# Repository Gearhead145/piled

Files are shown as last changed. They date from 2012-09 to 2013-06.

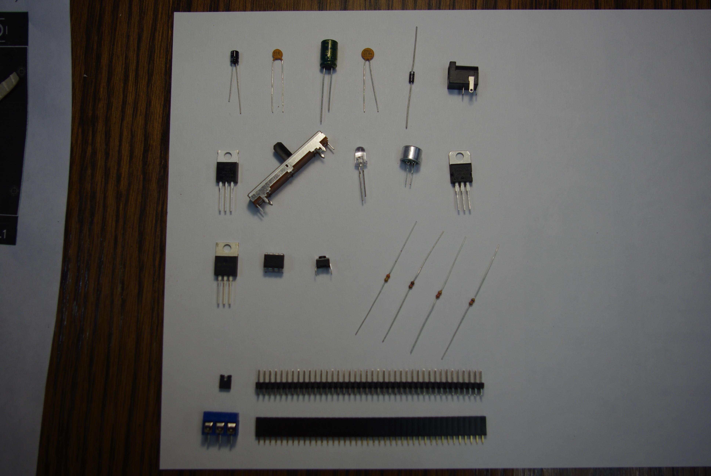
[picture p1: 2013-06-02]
Component Datasheets/PILED/113_0601/IMGP3082.JPG

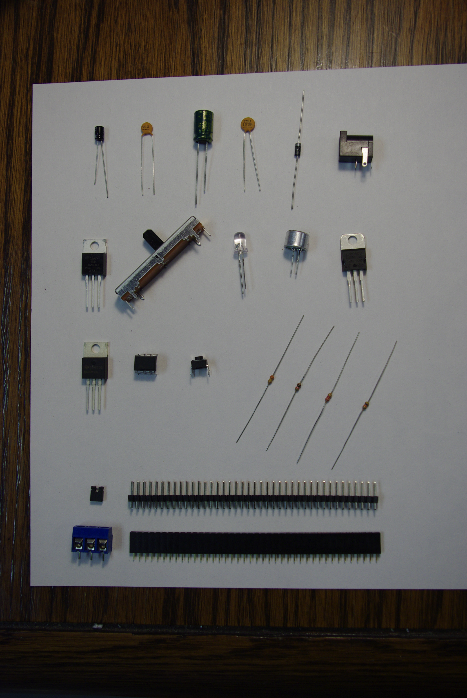
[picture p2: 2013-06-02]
Component Datasheets/PILED/113_0601/IMGP3088.JPG

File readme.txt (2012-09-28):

*Note - For best appearance, view with a monospaced font with word-wrap disabled* 

                 ___      _______  ______     _______  ___   ___      _______ 
                |   |    |       ||      |   |       ||   | |   |    |       |
                |   |    |    ___||  _    |  |_     _||   | |   |    |    ___|
                |   |    |   |___ | | |   |    |   |  |   | |   |    |   |___ 
                |   |___ |    ___|| |_|   |    |   |  |   | |   |___ |    ___|
                |       ||   |___ |       |    |   |  |   | |       ||   |___ 
                |_______||_______||______|     |___|  |___| |_______||_______|

                              More than just another LED desk lamp.

                          - An Open-Source Hardware/Software project -

The LED TILE is a MSP430G2553 based development board with integrated high current constant
voltage LED drivers, input sensors, and fully configurable I/O. Female headers allow easy addition
of sensors and other devices, while shorting blocks can be used to enable or disable any of the on-board 
devices (such as the LED Drivers or Microphone). On board voltage regulators produce 3.3V and 5V, which
are available via a female header for use with added circuits.

Hardware Features [Mainboard] :
	-3 channels (RGB) MOSFET based LED outputs (each 1.5A continuous!)
	-Electret microphone, LM386 based pre-amplifier, hardware envelope and low pass filters
	-Three linear potentiometers
	-Two pushbuttons
	-Female header sockets for EVERY PIN on the microcontroller, allowing easy connection of
		sensors and additional circuits (such as additional buttons, CdS cell, etc)
	-Double Male headers allow you to selectively connect or disconnect ANY pin on the
		microcontroller to the main board circuitry using shorting blocks. This is important
		if you want to use I/O pins from the LED TILE sensors (such as the potentiometers)
		for your own sensors and circuits.
	-Screw Terminals for Input Power (12V), Inter-Tile Serial Communication Lines, LED Outputs
	-On-board voltage regulators produce 3.3V and 5V (and unregulated 12V), which are available 
		via female header for simple interface of custom sensors to the LED TILE
	-Constructed using through-hole components - Even a beginner can solder this board together!
		(also available fully soldered. The processor is surface mount, and is always pre-soldered)

MSP430G2553 / Software Features:
	-8 channels of 10bit ADCs (for reading analog values into the microcontroller, such as those
		from potentiometers, light sensors, or audio)
	-24 General Purpose digital I/O pins (for attaching buttons, etc)
	-16Kb of program memory offers space for moderately large programs (for example, the current
		LIGHT TILE demo code, which has several modes, including a smooth RGB fade, an adjustable
		color temperature light source, an RGB mixer, a sound activated DJ style fading light,
		and a variable color/frequency/duty cycle strobe, uses under 3Kb of memory)
	-Internal (enable-able) pull up/down resistors makes attaching a button as simple as connecting
		it from a I/O pin to ground or VCC
	-Integrated hardware UART allows for inter-TILE communication with virtually no cpu overhead. 
		While primarily designed to allow an array of LED TILEs to act as pixels and display 
		patterns, the serial can be used for just about anything.
	-Write new code to make the LED TILE do cool things!
	-We have created helper functions to make tasks (such as reading analog values from sensors) 
		simple and intuitive
	-The processor runs at up to 16MHz (even running at 1MHz, the demo program runs fast enough to
		refresh the LEDs around 4000 times a second)
	-Can be easily programmed via the Spy-Bi-Wire interface. We reccomend using a TI Launchpad as 
		a programmer (these cost only $4.30, including shipping/handling). Simply attach the
		launchpad with four jumpers (VSS,GND,RST,TEST) to the LED TILE, and connect the launchpad
		USB cable to the computer. The free version of Code Composer Studio provides a robust
		IDE and compiler, and can be used to develop code for the LED TILE.

Hardware Features [LEDs and interface board] :
	-One LED TILE complete kit includes 5.5 feet of RGB LED tape. 5.5 feet has 100 LEDs (each of 
		which is an surface mount 5050 RGB LED)
			-RGB LED Specs [each individual LED]:
				-100mW per color (300mW if all three are fully on)
				-Luminous Intensity Red: 800mcd, Green: 1000mcd, Blue: 400mcd
	-LED Tape can be cut every 3 LEDs - use long strips for lighting computers, desks, etc.
	-LED Tape is self adhesive and flexible, allowing creative mounting...
	-The LED TILE LED Interface Board can be used to connect 9 strips (each of 9 leds) to form an
		array of 81 LEDs. This is bright enough to be used as a small desk lamp, and can easily
		provide mood/accent light for a decent sized room. This board has solder pads for each
		strip, which eliminates the need to cut many pieces of wire.

******************************************************************************************************
*           LED TILE Mainboard: Schematic layout of interface components/sensors                     *
******************************************************************************************************
*                                                                                                    *
*                                                                                                    *
*             ┌────Three linear potentiometers [available as analog inputs to the microcontroller]   *
*             │                                                                                      *
*             │                                                                                      *
*         ┌───┼───┐  Two tactile switches          ┌──Female headers for 3.3V,5V,12V,GND             *
*         │   │   │        │                       │                                                 *
*       __│___│___│________│_______________________│_______                                          *
*      | _v  _v  _v   __   │                    ◘  │    [+]<─┐                                       *
*      ||  ||▐▌||  | |()|<─┤                    ◘<─┘    [+]<─┤                                       *
*      ||  ||▐▌||  | |__|  │                    ◘       [+]<─┤                                       *
*      ||  ||  ||  |       │                    ◘       [+]<─┼───Screw terminals for                 *
*      ||▐▌||  ||  |       │       ::::::::::::::<─┐    [+]<─┤   Input Power,Inter-Tile Serial,LEDS  *
*      ||▐▌||  ||  |       │  ┌───>◘◘◘◘◘◘◘◘◘◘◘◘◘◘  │    [+]<─┤                                       *
*      ||  ||  ||  |       │  │    ____            │    [+]<─┤                                       *
*      ||  ||  ||  |       │  │   /    \           │    [+]<─┘                                       *
*      ||  ||  ||  |       │  │   |Mic.|           │       |                                         *
*      ||  ||  ||  |       │  │   \____/           │       |                                         *
*      ||  ||  ||  |       │  │                    │       |                                         *
*      ||  ||  ||▐▌|  __   │  ├───>◘◘◘◘◘◘◘◘◘◘◘◘◘◘  │       |                                         *
*      ||  ||  ||▐▌| |()|<─┘  │    ::::::::::::::<─┤       |                                         *
*      ||__||__||__| |__|     │                    │       |                                         *
*      |______________________│____________________│_______|                                         *
*                             │                    │                                                 *
*                 Single female headers      Double male headers                                     *
*                 Easily attach DIY sensors  [Enable/disable on-board devices]                       *
*                                                                                                    *
******************************************************************************************************

******************************************************************************************************
*                           LED TILE LightBoard: Interface Schematic                                 *
******************************************************************************************************
*   ┌────────────────────────────────────────────────────────────────────────────────────────┬────┐  *
*   │                                                                                        │    │  *
*   v________________________________________________________________________________________v    │  *
*  |○                                                                                        ○|   │  *
*  |○                                                                                        ○|   │  *
*  |○                                                                                        ○|   │  *
*  |○__⌂⌂⌂⌂______⌂⌂⌂⌂______⌂⌂⌂⌂______⌂⌂⌂⌂______⌂⌂⌂⌂______⌂⌂⌂⌂______⌂⌂⌂⌂______⌂⌂⌂⌂______⌂⌂⌂⌂__○|   │  *
*        ^         ^         ^         ^         ^         ^         ^         ^         ^        │  *
*        │         │         │         │         │         │         │         │         │        │  *
*        ├─────────┴─────────┴─────────┴─────────┴─────────┴─────────┴─────────┴─────────┘        │  *
*        │                                                                                        │  *
*        └── Solder pads to connect individual strips of LED Tape                                 │  *
*                                                                                                 │  *
*                                           Drilled solder pad connections for LED TILE Mainboard─┘  *
*                                                                                                    *
******************************************************************************************************

******************************************************************************************************
*                LED TILE LightBoard: Suggested LED Configuration [ 81 RGB LEDs]                     *
******************************************************************************************************
*                                                                                                    *
*     __________________________________________________________________________________________     *
*    |○                                                                                        ○|    *
*    |○                                                                                        ○|    *
*    |○                                                                                        ○|    *
*    |○__⌂⌂⌂⌂______⌂⌂⌂⌂______⌂⌂⌂⌂______⌂⌂⌂⌂______⌂⌂⌂⌂______⌂⌂⌂⌂______⌂⌂⌂⌂______⌂⌂⌂⌂______⌂⌂⌂⌂__○|    *
*       |    |    |    |    |    |    |    |    |    |    |    |    |    |    |    |    |    |       *
*       |┌──┐|    |┌──┐|    |┌──┐|    |┌──┐|    |┌──┐|    |┌──┐|    |┌──┐|    |┌──┐|    |┌──┐|       *
*       |└──┘|    |└──┘|    |└──┘|    |└──┘|    |└──┘|    |└──┘|    |└──┘|    |└──┘|    |└──┘|       *
*       |    |    |    |    |    |    |    |    |    |    |    |    |    |    |    |    |    |       *
*       |    |    |    |    |    |    |    |    |    |    |    |    |    |    |    |    |    |       *
*       |    |    |    |    |    |    |    |    |    |    |    |    |    |    |    |    |    |       *
*       |┌──┐|    |┌──┐|    |┌──┐|    |┌──┐|    |┌──┐|    |┌──┐|    |┌──┐|    |┌──┐|    |┌──┐|       *
*       |└──┘|    |└──┘|    |└──┘|    |└──┘|    |└──┘|    |└──┘|    |└──┘|    |└──┘|    |└──┘|       *
*       |    |    |    |    |    |    |    |    |    |    |    |    |    |    |    |    |    |       *
*       |    |    |    |    |    |    |    |    |    |    |    |    |    |    |    |    |    |       *
*       |    |    |    |    |    |    |    |    |    |    |    |    |    |    |    |    |    |       *
*       |┌──┐|    |┌──┐|    |┌──┐|    |┌──┐|    |┌──┐|    |┌──┐|    |┌──┐|    |┌──┐|    |┌──┐|       *
*       |└──┘|    |└──┘|    |└──┘|    |└──┘|    |└──┘|    |└──┘|    |└──┘|    |└──┘|    |└──┘|       *
*       |    |    |    |    |    |    |    |    |    |    |    |    |    |    |    |    |    |       *
*       |    |    |    |    |    |    |    |    |    |    |    |    |    |    |    |    |    |       *
*       |    |    |    |    |    |    |    |    |    |    |    |    |    |    |    |    |    |       *
*       |┌──┐|    |┌──┐|    |┌──┐|    |┌──┐|    |┌──┐|    |┌──┐|    |┌──┐|    |┌──┐|    |┌──┐|       *
*       |└──┘|    |└──┘|    |└──┘|    |└──┘|    |└──┘|    |└──┘|    |└──┘|    |└──┘|    |└──┘|       *
*       |    |    |    |    |    |    |    |    |    |    |    |    |    |    |    |    |    |       *
*       |    |    |    |    |    |    |    |    |    |    |    |    |    |    |    |    |    |       *
*       |    |    |    |    |    |    |    |    |    |    |    |    |    |    |    |    |    |       *
*       |┌──┐|    |┌──┐|    |┌──┐|    |┌──┐|    |┌──┐|    |┌──┐|    |┌──┐|    |┌──┐|    |┌──┐|       *
*       |└──┘|    |└──┘|    |└──┘|    |└──┘|    |└──┘|    |└──┘|    |└──┘|    |└──┘|    |└──┘|       *
*       |    |    |    |    |    |    |    |    |    |    |    |    |    |    |    |    |    |       *
*       |    |    |    |    |    |    |    |    |    |    |    |    |    |    |    |    |    |       *
*       |    |    |    |    |    |    |    |    |    |    |    |    |    |    |    |    |    |       *
*       |┌──┐|    |┌──┐|    |┌──┐|    |┌──┐|    |┌──┐|    |┌──┐|    |┌──┐|    |┌──┐|    |┌──┐|       *
*       |└──┘|    |└──┘|    |└──┘|    |└──┘|    |└──┘|    |└──┘|    |└──┘|    |└──┘|    |└──┘|       *
*       |    |    |    |    |    |    |    |    |    |    |    |    |    |    |    |    |    |       *
*       |    |    |    |    |    |    |    |    |    |    |    |    |    |    |    |    |    |       *
*       |    |    |    |    |    |    |    |    |    |    |    |    |    |    |    |    |    |       *
*       |┌──┐|    |┌──┐|    |┌──┐|    |┌──┐|    |┌──┐|    |┌──┐|    |┌──┐|    |┌──┐|    |┌──┐|       *
*       |└──┘|    |└──┘|    |└──┘|    |└──┘|    |└──┘|    |└──┘|    |└──┘|    |└──┘|    |└──┘|       *
*       |    |    |    |    |    |    |    |    |    |    |    |    |    |    |    |    |    |       *
*       |    |    |    |    |    |    |    |    |    |    |    |    |    |    |    |    |    |       *
*       |    |    |    |    |    |    |    |    |    |    |    |    |    |    |    |    |    |       *
*       |┌──┐|    |┌──┐|    |┌──┐|    |┌──┐|    |┌──┐|    |┌──┐|    |┌──┐|    |┌──┐|    |┌──┐|       *
*       |└──┘|    |└──┘|    |└──┘|    |└──┘|    |└──┘|    |└──┘|    |└──┘|    |└──┘|    |└──┘|       *
*       |    |    |    |    |    |    |    |    |    |    |    |    |    |    |    |    |    |       *
*       |    |    |    |    |    |    |    |    |    |    |    |    |    |    |    |    |    |       *
*       |    |    |    |    |    |    |    |    |    |    |    |    |    |    |    |    |    |       *
*       |┌──┐|    |┌──┐|    |┌──┐|    |┌──┐|    |┌──┐|    |┌──┐|    |┌──┐|    |┌──┐|    |┌──┐|       *
*       |└──┘|    |└──┘|    |└──┘|    |└──┘|    |└──┘|    |└──┘|    |└──┘|    |└──┘|    |└──┘|       *
*       |    |    |    |    |    |    |    |    |    |    |    |    |    |    |    |    |    |       *
*       |____|    |____|    |____|    |____|    |____|    |____|    |____|    |____|    |____|       *
*                                                                                                    *
*                                                                                                    *
******************************************************************************************************

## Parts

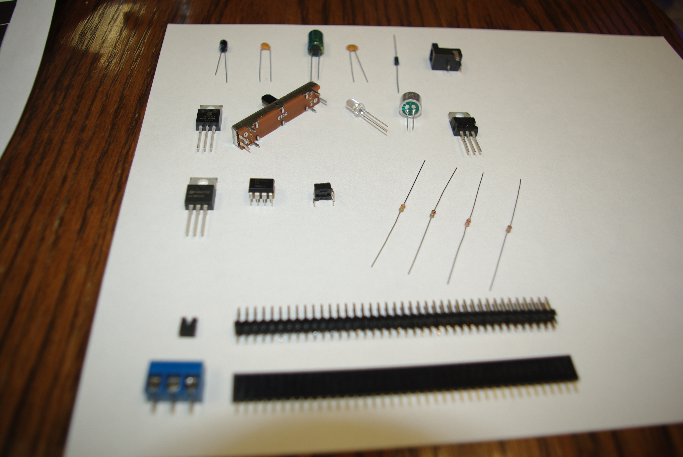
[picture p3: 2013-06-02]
Component Datasheets/PILED/113_0601/IMGP3078.JPG

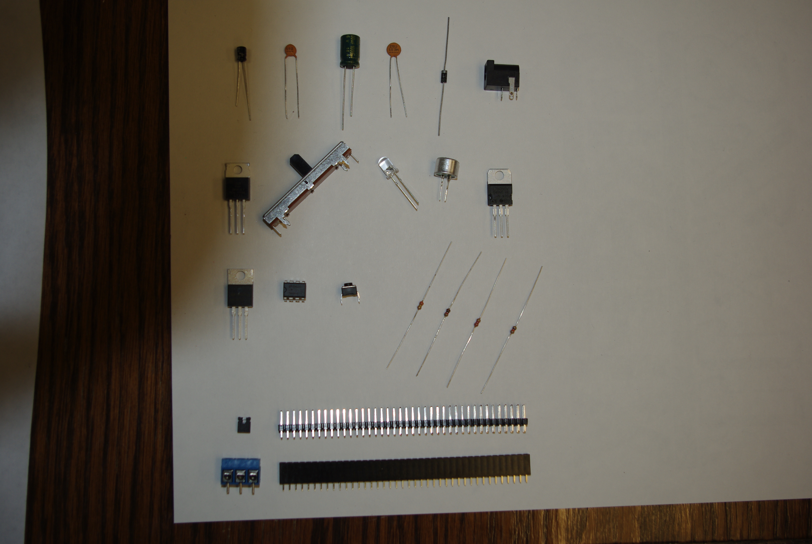
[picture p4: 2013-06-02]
Component Datasheets/PILED/113_0601/IMGP3077.JPG

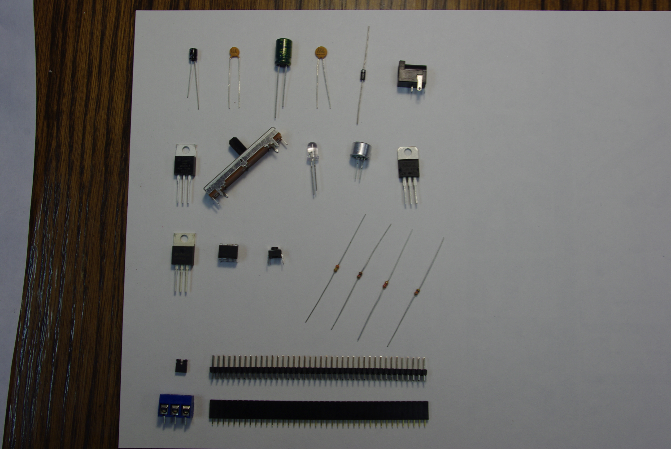
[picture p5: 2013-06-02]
Component Datasheets/PILED/113_0601/IMGP3084.JPG

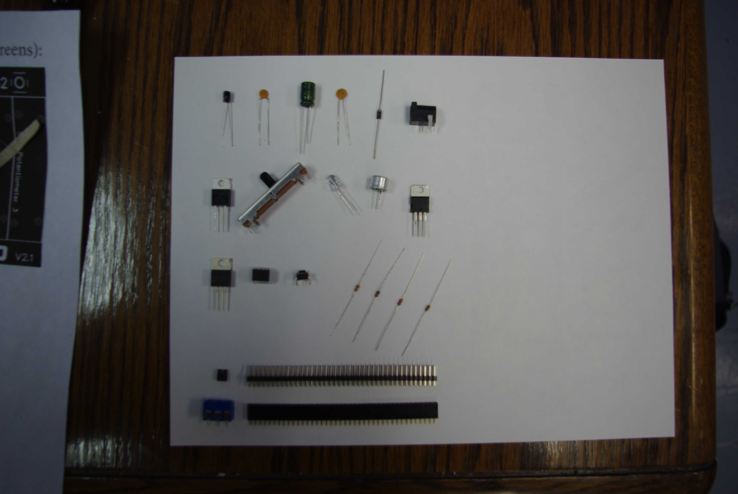
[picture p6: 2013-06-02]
Component Datasheets/PILED/113_0601/IMGP3081.JPG

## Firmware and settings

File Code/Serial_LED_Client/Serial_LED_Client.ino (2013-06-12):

#include "test.h" //Include VITAL RGB TILE FUNCTIONS!
#define mode_max 6//Define the maximum number of modes, so the pushbuttons will iterate through them all properly. Mode 0 is direct bluetooth command, and Mode 1 is the default start-up mode (rgb mixer). 
unsigned char mode = 1; //Global mode variable allows board to save/switch between different operating modes.


//Settings for strobe
char s_r = 255;
char s_g = 255;
char s_b = 255;

//setting for sound activated colors
char ccolor = 0;
int avg = 1023; //variable for keeping a running average of the sound levels. Start at 1023 to prevent accidental triggering in a low volume situation

//setting for rainbow fade
// global variables
unsigned int rbow;     //0-360
unsigned int relative; //0-59
unsigned char rr, rg, rb;

//setting for clap activated white light
boolean clapper = 0;


void _set_rgb(char command[128], char command_length, char base_length){
  //parse out the individual strings
  char temp_num[4]; //3 chars, plus a null character to terminate it as a string for atoi()
  char color = 2;
  char pos;
  char temp = command_length - 3; //we want an index of the leftmost data value (not ")" or ";" )
  unsigned char r,g,b;
  while ( temp > base_length){
     temp_num[0] = '0';//clear the buffer for a single color
     temp_num[1] = '0';
     temp_num[2] = '0';
     temp_num[3] = 0; //null character termination
     pos = 2;
    while (command[temp] != ',' && command[temp] != '('){ //parse out separate colors
        temp_num[pos] = command[temp]; //data? I hope so!
        temp--;
        pos--;
        if (pos<-1) { //You forgot a comma, or put WAY too many digits...
           invalid_input();
           return;
        }
    }
    temp--;

    //the temp_num array should now contain a 3 digit padded null terminated ascii representation of a number
    if (color == 2) b = atoi(temp_num);
    if (color == 1) g = atoi(temp_num);
    if (color == 0) r = atoi(temp_num);
    color--; //now read in the next color   
  }
  set_rgb(r,g,b);
}


void _target_rgb(char command[128], char command_length, char base_length){
  
  //!!! THIS IS A BLOCKING COMMAND!!!
 
  //parse out the individual strings
  char temp_num[11]; //10 chars, plus a null character to terminate it as a string for atoi()
  char color = 3; //color here also includes the target time
  char pos;
  char temp = command_length - 3; //we want an index of the leftmost data value (not ")" or ";" )
  unsigned char r,g,b;
  unsigned int t; //store the target fade time
  
  while ( temp > base_length){
     temp_num[0] = '0';//clear the buffer for a single color
     temp_num[1] = '0';
     temp_num[2] = '0';
     temp_num[3] = '0';
     temp_num[4] = '0';
     temp_num[5] = '0';
     temp_num[6] = '0';
     temp_num[7] = '0';
     temp_num[8] = '0';
     temp_num[9] = '0';
     temp_num[10] = '0';
     temp_num[11] = 0; //null character termination
     pos = 10;
    while (command[temp] != ',' && command[temp] != '('){ //parse out separate colors
        temp_num[pos] = command[temp]; //data? I hope so!
        temp--;
        pos--;
        if (pos<-1) { //You forgot a comma, or put WAY too many digits...
           invalid_input();
           return;
        }
    }
    temp--;

    //the temp_num array should now contain a 3 digit padded null terminated ascii representation of a number
    if (color == 3) t = atoi(temp_num);
    if (color == 2) b = atoi(temp_num);
    if (color == 1) g = atoi(temp_num);
    if (color == 0) r = atoi(temp_num);
    color--; //now read in the next color   
  }
  target_rgb(r,g,b,t);  
}

void reboot(){
  set_rgb(0,0,0);
  s_r = 255;
  s_g = 255;
  s_b = 255;
  avg = 1023;//reset the sound average.
  setup();
}


 void invalid_input(){
   Serial.println("Error in input command. Type ""help();"" for available commands."); 
 }

void establishContact() {
  Serial.println(" _______  ___   ___      _______  ______"); 
  Serial.println("|       ||   | |   |    |       ||      |");
  Serial.println("|    _  ||   | |   |    |    ___||  _    |");
  Serial.println("|   |_| ||   | |   |    |   |___ | | |   |");
  Serial.println("|    ___||   | |   |___ |    ___|| |_|   |");
  Serial.println("|   |    |   | |       ||   |___ |       |");
  Serial.println("|___|    |___| |_______||_______||______|");
  Serial.println("\nSerial command shell v1.2");
  Serial.println("Copyright 2012 LIB3 Inc.");
  Serial.println("__________________________________________\n\n");
  Serial.print('>');
}



//dec_mode and inc_mode serve as the ISR functions for the two pushbuttons
void dec_mode(){
  mode--;
  if (mode == 0){
    mode = mode_max; //if we cycle to the end, continue at other end
  }
}

void inc_mode(){
  mode++;
  if (mode > mode_max){
    mode = 1;
  }  
}


void setup()
{
       setup_piled();
       mode = 1;          //Defaults to RGB mixer mode. 
       establishContact();  // send the fun initialization data OUT     
}

void loop()
{
  //Variables for serial parsing
char command[32]; //command buffer
int command_length = 0; //length of command (ending with a ;)
char command_temp = 0;
int base_length = 0;
  //Check mode, and do mode-specific stuff\
  
  while (1){
    
  int i;
  {
    switch (mode){
          case 0:{ // Direct bluetooth command mode. Do nothing - just wait for commands
            break;
          }
          case 1:
            set_rgb(analogRead(F1)/4, analogRead(F2)/4, analogRead(F3)/4);
            break;
          case 2: //the Clapper (named after Zach Clapper, creator of the first PILED Android app)
            {
            int threshold = analogRead(F1); //set the threshold from the F1 potentiometer. This is the level against which the mic signal is compared to detect transients
            int temp = analogRead(MIC);//value from 0-1023 indicating sound level. Room noise is around 100-150 with the air conditioner on... :D
      
      	    if (temp>threshold){ //if level is over threshold, it's a beat!
             //Clap on, clap off...
             if (clapper) {
               target_rgb((char)0,(char)0,(char)0,(unsigned int)200);
               clapper = 0;
             }
             else{
               target_rgb((char)255,(char)255,(char)255,(unsigned int)200);
               clapper = 1;
             }
            }
            break;
            }
          case 3:{
            int margin = analogRead(F1) / 16;//set the margin from the F1 potentiometer. This is the difference in the average level and a transient to trigger a beat.
            int temp = analogRead(MIC);//value from 0-1023 indicating sound level. Room noise is around 100-150 with the air conditioner on... :D
            avg  = (temp + 3*avg)/4; //commence with super simple running exponential averaging!  
      	    if (temp>(avg + margin)){ //if level is over average plus margin, it's a beat! (most of the time)   
              //Cycle through the colors
              if (ccolor == 2){
                 target_rgb((char)255,(char)0,(char)0,(unsigned int)10);
                 ccolor = 0;
               }              
               else if (ccolor == 1){
                 target_rgb((char)0,(char)255,(char)0,(unsigned int)10);
                 ccolor= 2;
               }
               else{
                  target_rgb((char)0,(char)0,(char)255,(unsigned int)10);
                  ccolor = 1;
               }
            }
            break;
          }
          case 4: //Color temperature fader F1
          {
            unsigned int ctemp = (analogRead(F1) / 8)-64;
            unsigned int bright = analogRead(F2)/4;
            set_rgb((bright*(191-ctemp))/256,(bright*(191))/256,(bright*(150+ctemp))/256);
            break;
          }
  	  case 5:
           {
            //strobe - with variable frequency, duty cycle, and color
            int ontime = analogRead(F1);
            int offtime = analogRead(F2);
            
	    sleep(offtime);//this is your off time...
            set_rgb(s_r,s_g,s_b); //Set the colors ON as requested...
	    sleep(ontime);//this is your on cycle time...
	    set_rgb(0,0,0);
            break;
           }
          case 6:
          {
            sleep(analogRead(F1)/64);
            rbow++;
            rbow %= 360;
            char category = rbow / 60;
            int relative = rbow % 60;
            switch(category){
              case 0:
                rr = 255;
                 rb = 0;
                 rg = relative * 17 / 4;
                           break;
              case 1:
                  rg = 255;
                  rb = 0;
                  rr = 255 - relative * 17 / 4;
                  break;
              case 2:
                  rg = 255;
                  rr = 0;
                  rb = relative * 17 / 4;
                  break;
              case 3:
                  rb = 255;
                  rr = 0;
                  rg = 255 - relative * 17 / 4;
                  break;
              case 4:
                  rb = 255;
                  rg = 0;
                  rr = relative * 17 / 4;
                  break;
              case 5:
                  rr = 255;
                  rg = 0;
                  rb = 255 - relative * 17 / 4;
                  break;
              }
              set_rgb(rr,rg,rb);
			  break;
          }     
    }
  }
  
  
   
  //check for serial stuff... Max length is 32 chars
  
    if (Serial.available() != 0){ //if there is a character in the serial buffer, check it!
      while (command_temp != ';'){
        command_temp = Serial.read();
        if (command_temp == ' ' || command_temp <= 31 || command_temp == '/r' || command_temp == '/n' ){
          //character is spacing/formatting, and should be ignored. Do nothing.
        }
        else { //character is valid, and should be treated as such...
          command[command_length] = command_temp;
          ++command_length; //update the recorded length of the command so far
          if (command_temp == '('){
            //This is the end of the base command, and the start of arguments
            base_length = command_length - 1;
          }
        }
      }
      if (command_temp == ';'){
        //We have a new command (perhaps!)
        //Now check which commands were requested! set_rgb, target_rgb, rgbmix, reboot, strobe, clapper

    
          if (!memcmp("target_rgb",command,10)){
            mode = 0;
             _target_rgb(command, command_length, base_length);
             //Prepare the console for a new command!
              command_length = 0; //length of command (ending with a ;)
              command_temp = 0;
              base_length = 0;
              Serial.write('\n>');
          }
          else if (!memcmp("set_rgb",command,7)){
            mode = 0;
            _set_rgb(command, command_length, base_length);
              //Prepare the console for a new command!
              command_length = 0; //length of command (ending with a ;)
              command_temp = 0;
              base_length = 0;
              Serial.write('\n>');
          }
          else if (!memcmp("rgbmix",command,6)){
            mode = 1; //set the mode to manual RGB faders
              command_length = 0; //length of command (ending with a ;)
              command_temp = 0;
              base_length = 0;
              Serial.write('\n>');
          }
          else if (!memcmp("clapper",command,7)){
            mode = 2; //set the mode to clap activated
              //Prepare the console for a new command!
              command_length = 0; //length of command (ending with a ;)
              command_temp = 0;
              base_length = 0;
              Serial.write('\n>');
          }
          
          else if (!memcmp("sound",command,5)){
            mode = 3; //set the mode to sound activated
              //Prepare the console for a new command!
              command_length = 0; //length of command (ending with a ;)
              command_temp = 0;
              base_length = 0;
              Serial.write('\n>');
          }
          else if (!memcmp("color_temp",command,10)){
            mode = 4; //set the mode to manual color temperature control
              //Prepare the console for a new command!
              command_length = 0; //length of command (ending with a ;)
              command_temp = 0;
              base_length = 0;
              Serial.write('\n>');
          }
          else if (!memcmp("rainbow",command,7)){
            mode = 6; //set the mode to demo rainbow mode
              //Prepare the console for a new command!
              command_length = 0; //length of command (ending with a ;)
              command_temp = 0;
              base_length = 0;
              Serial.write('\n>');
          }
          else if (!memcmp("strobe",command,6)){
            mode = 5; //set the mode to STROBE MODE (manual settings)
              //Prepare the console for a new command!
              command_length = 0; //length of command (ending with a ;)
              command_temp = 0;
              base_length = 0;
              Serial.write('\n>');
          }
          else if (!memcmp("reboot",command,6)){
              reboot();
              //Prepare the console for a new command!
              command_length = 0; //length of command (ending with a ;)
              command_temp = 0;
              base_length = 0;
              
          }   
          else {
            invalid_input();
              //Prepare the console for a new command!
              command_length = 0; //length of command (ending with a ;)
              command_temp = 0;
              base_length = 0;
              Serial.write('\n>');
          }                  
      }    
    }  
  }
}

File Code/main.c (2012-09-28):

//***************************************************************************************
//  MSP430 RGB LED Tile Control Software
//	Copyright 2012 Jorel Lalicki
//
//***************************************************************************************

//Board System Devices Port/Pin Numbers - These are NOT AVAILABLE FOR GENERAL USE unless disabled using shorting blocks:
// Port 1: ALL PINS
// Port 2: Pins 0,1,4



//Defines the on-board devices
//#define F1 INCH_7
//#define F2 INCH_5
//#define F3 INCH_4
//#define MIC INCH_0
//#define S1 BIT3 //Port 1
//#define S2 BIT0 //Port 2
//#define R BIT6 //Port 1
//#define G BIT1 //Port 2
//#define B BIT4 //Port 2



#include <msp430.h>				
#include "led_tile.h"
#include <stdlib.h>
//#include "launchpad_helpers.h"
int tempe;
char mode; //this global variable stores the current mode the LED TILE is operating in.
char rt;

//used for sound activated color rolling window averaging
char average[100];
char counter;


int main(void) //Program execution begins here:
{
	P1DIR &= ~BIT0;
	P1OUT &= ~BIT0;

	rt = 0;

	mode = 3; //This is the mode that the LED TILE will start in
	counter = 0;
	init();

  while(1){

	  int i;

   switch (mode){
  	  case 0:   {		  //very slow rgb fade

  			  target_rgb(255,0,0,1000000);
  			if (mode!= 0)break;

  			  target_rgb(255,255,0,1000000);
  			if (mode!= 0)break;

  			  target_rgb(0,255,0,1000000);
  			if (mode!= 0)break;

  			  target_rgb(0,255,255,1000000);
  			if (mode!= 0)break;

  			  target_rgb(0,0,255,1000000);
  			if (mode!= 0)break;

  			  target_rgb(255,0,255,1000000);
  		  break;
  	  }
//  	  case 1: //Sound Activated Color Thing! Quiet = blue, loud = RED
//  	  {
//  		  float gain = (float)Single_Measure(F1)/16+1; //set the gain from the R potentiometer - range 0-63
//  		  int threshold = Single_Measure(F2);//set the threshold from the R potentiometer
//  		  int temp = (Single_Measure(MIC));//value from 0-1023 indicating sound level. Room noise is around 100-150 with the air conditioner on... :D
//  		  temp -= threshold; //get rid of the ambient level
//  		  if (temp <0)temp=0; //if negative, make zero (leds cant show negative light)
//  		  temp*=gain; //multiply the level by 10 to get closer to the full LED brightness range
//  		  if (temp>255)temp=255; //if over the max level, make only the max level
//  		  //Keep a running average of 5 samples - this helps reduce flickering
//  		  int avg = 0;
//  		  int i;
//  		  for (i = 0; i < 100; i++){
//  			  avg += average[i];
//  		  }
//  		  avg /= 100;
//  		  average[counter] = temp;
//  		  counter++;
//  		  if (counter>=5)counter = 0;
//  		  target_rgb(255-avg,0,avg,1000);
//  		  break;
//  	  }
  	  case 1: //color temperature adjustment
  	  {
  		  int temp;
  		  temp = Single_Measure(F1) / 4;
  		  signed char offset = ((signed)temp - 128) / 2; //produce a signed offset that indicates "how far" to either side of "pure white"
  		  	  	  	  	  	  	  	  	  	  	  	  	 //INCH_7 is
  		  set_rgb(255-64+offset, 255-96,255-64-offset); //add the offset to the red, subtract it from the blue. More blue is a 'cooler'
  		  	  	  	  	  	  	  	  	  	  	  	  	//color temp.; more red is a 'warmer' color.
  		  break;
  	  }
  	  case 2: //Three knob color mixer
  		  //Using INCH_4, INCH_7 and INCH_5 for Red, Blue and Green components respectively
  	  {
  		  set_rgb((Single_Measure(F1) / 4), (Single_Measure(F2) / 4),(Single_Measure(F3) / 4));
  		  break;
  	  }
  	  case 4://strobe - with variable frequency, duty cycle, and color
  	{
  			for(i = 0; i < (float)(Single_Measure(F1))*(float)(Single_Measure(F2))/1024; ++i){
  				sleep(1000);//this is your frequency...
  		        }

  		  		int color = (Single_Measure(F3)) / 147;//grab the "hue" value, divide it up to give 7 values
  		  	  switch (color){ //select an output color based on the reading from F3
  		  	  	  	  	  	  //divide it into 7 discrete colors instead of a continuous spectrum
  		  	  case 0:
  		  		  set_rgb(255,0,0);
  		  		  break;
  		  	  case 1:
  		  		  set_rgb(0,255,0);
  		  		  break;

  		  	  case 2:
  		  		  set_rgb(0,0,255);
  		  		  break;

  		  	  case 3:
  		  		  set_rgb(255,255,0);
  		  		  break;

  		  	  case 4:
  		  		  set_rgb(255,0,255);
  		  		  break;

  		  	  case 5:
  		  		  set_rgb(0,255,255);
  		  		  break;

  		  	  case 6:
  		  		  set_rgb(255,255,255);
  		  		  break;
  		  	  }
  		  		for(i = 0; i < (float)(Single_Measure(F1))*(1-((float)(Single_Measure(F2))/1024)); ++i){
  		  			__delay_cycles(1000);//this is your duty cycle time...
  		  		}
  		  		set_rgb(0,0,0);
  		  break;
  	}
  	  case 3: //color fade to beat of music...
  	  {
  		  __delay_cycles(300000);
  		  int gain = 2;//_Single_Measure(F2)/16; //set the gain from the G potentiometer - range 0-63
  		  int threshold = _Single_Measure(F1);//set the threshold from the R potentiometer
  		  int temp = (_Single_Measure(MIC));//value from 0-1023 indicating sound level. Room noise is around 100-150 with the air conditioner on... :D
  		  temp -= threshold; //get rid of the ambient level
  		  if (temp <0)temp=0; //if negative, make zero (leds cant show negative light)
  		  temp*=gain; //multiply the level by 10 to get closer to the full LED brightness range
  		  if (temp>=255){//if the level is loud enough, it 'must' be a beat. HIT IT
  			  if (rt==0){
  				  //the color is red
  				target_rgb(255,0,0,200000);
  				++rt;
  			  }
  			  else if (rt == 1){
  				  //the color is green
  				target_rgb(0,255,0,200000);
  				++rt;
  			  }
  			  else if (rt == 2){
  				  //the color is blue
  				target_rgb(0,0,255,200000);
  				rt = 0;
  			  }
  		  }
  		  break;
  	  }
  	  }
  }
  }


// Port 1 interrupt service routine
#pragma vector=PORT1_VECTOR
__interrupt void Port_1(void)
{
   mode++;
   if (mode >=4) mode = 0;
   P1IFG &=~BIT3;                        // P1.3 IFG cleared
}

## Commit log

2013-01-11 Started updating components with new footprints, etc. Still needs new bluetooth module footprint, and final routing/silks.
2013-01-12 Added footprint/symbols for new bluetooth modules.
2013-01-13 Updated schematic/pcb layout with a variety of changes, including correcting the linear potentiometers (again...), adding in the reset pull up resistor, a power smoothing cap, and adjusting the bluet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
2013-01-13 Added footprint for DC barrel jack; rearranged everything so it could fit...
2013-01-13 A few more adjustments of positions. High current parts now have calculated trace widths for 10A with a 2oz copper. Silks are not finished yet.
2013-01-14 Added a LED strip connector PCB. (RFQs are out for it right now...we will need ALOT of these, as the 15x15 PILED kit requires 5). Made a few small adjustments to component footprints, and worked on p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
    [BoardOutline.gbr, Bottom.gbr, BottomMask.gbr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]
2013-03-12 Finally committed the gerbers (and final updates to the PCB) to the repo!
    [BoardOutline.gbr, Bottom.gbr, BottomMask.gbr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]
2013-05-05 Release Firmware: Both bluetooth and manual control, all in one device... Added: Bluetooth control Interruptable commands Sound activated color changing "Zach" Clapper sound activated light Super fli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
    [Serial_LED_Client.ino, test.h]
2013-05-12 Updated a bunch of stuff...really close to release ready... Buttons now work to change between modes. PWM frequency is quadrupled to 16kHz, and clock frequency is doubled (now 16MHz) Strobe broken (s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
    [Serial_LED_Client.ino, test.h]
2013-05-18 Fixed bugs, now everything works except the all new "rainbow fade" demo mode...
    [Serial_LED_Client.ino, test.h]
2013-05-19 Added values to the debouncing capacitors, and rearranged components to make it a bit neater.
2013-05-20 Basic parts list/datasheet; "committing the correct version this time" of the board layout with updates.
2013-05-27 Added some documentation, and an awesome open source soldering tutorial.
2013-06-05 Added resistors tutorial.
2013-06-07 Added assembly steps outline, glossary.
2013-06-08 updates and such...half the steps for assembly totally complete, plus most of the appendix/glossary
2013-06-14 Updated some data sheets/documentation for the PILED board.
